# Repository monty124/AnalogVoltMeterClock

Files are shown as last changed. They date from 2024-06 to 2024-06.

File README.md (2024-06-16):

# AnalogVoltMeterClock
An AnalogVoltMeterClock 🤷‍♂️

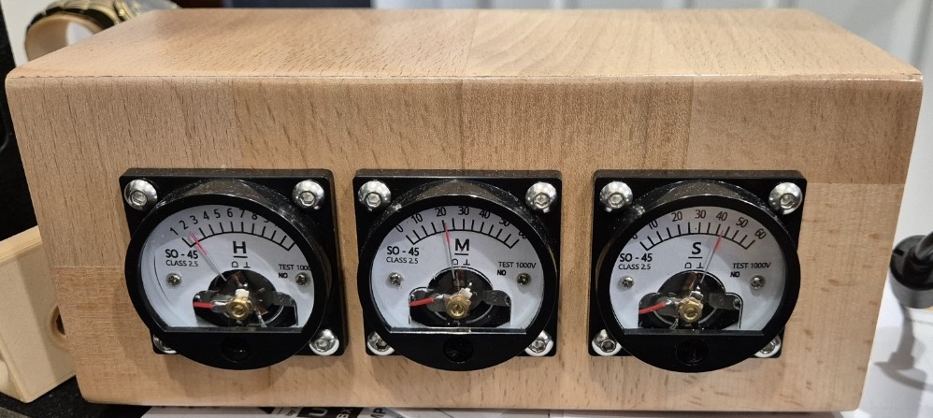
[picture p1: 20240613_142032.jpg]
  

# What is this?
Just a fun project to show the time in another way

Inspiration from:

- https://hackaday.io/project/163977-esp8266-wifi-ntp-voltmeter-clock
- https://michaelteeuw.nl/post/what-time-is-it-fathers-day
- https://github.com/MichMich/AnalogVoltMeterClock

# I want one

Sure, youll need:

### BOM

- An Enclosure, it needs to be big enough to fit the analog dials as well as the PCB (100x60) <br>
  There is a printable one that MAY work here https://www.thingiverse.com/thing:3437800 BUT i am unsure if my PCB will fit this enclosure. Zip Files are committed in this git repo if you want to try it; OR build without the PCB and hard wire to the ESP module and use this one.
- Optional 3D printed back or solid back, (make room for your power connection!)
- 3x Analog Voltmeter SO-45 style gauges (voltage unimportant) <br>
  https://www.aliexpress.com/item/1005003489268646.html <br>
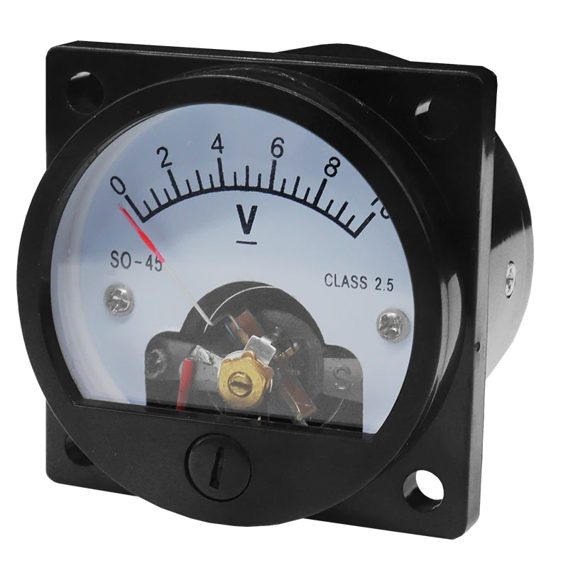
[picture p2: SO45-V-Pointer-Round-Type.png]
  
- 3x 3.9K Resistors OR any value between 2 - 5 K however you will need to work out your own calibration matrix
- PCB (gerber files are included [here](/AnalogVoltMeterClock/Gerber))
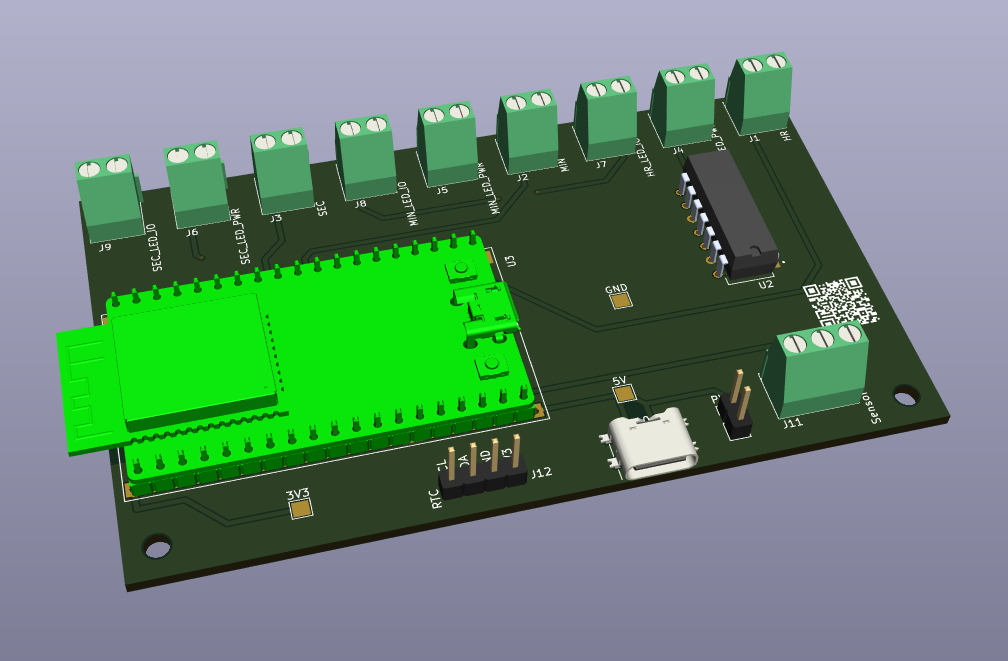
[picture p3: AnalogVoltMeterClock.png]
  
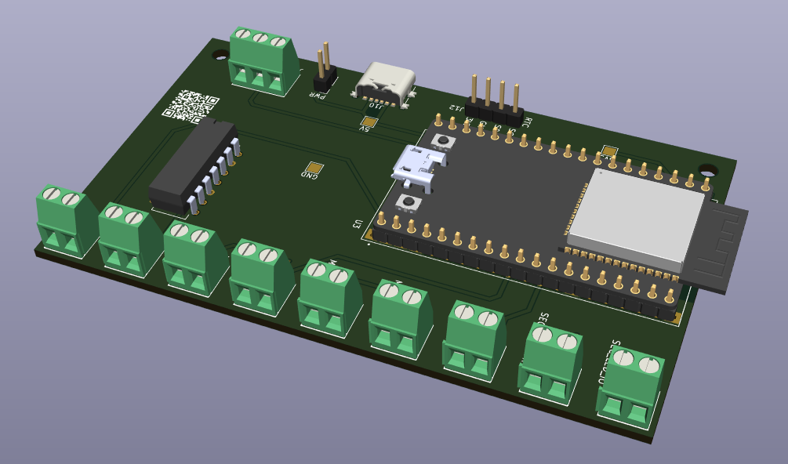
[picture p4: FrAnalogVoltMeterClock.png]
  
- "SW-420" Vibration Sensor <br>
  https://www.aliexpress.com/item/1005006205428052.html <br>
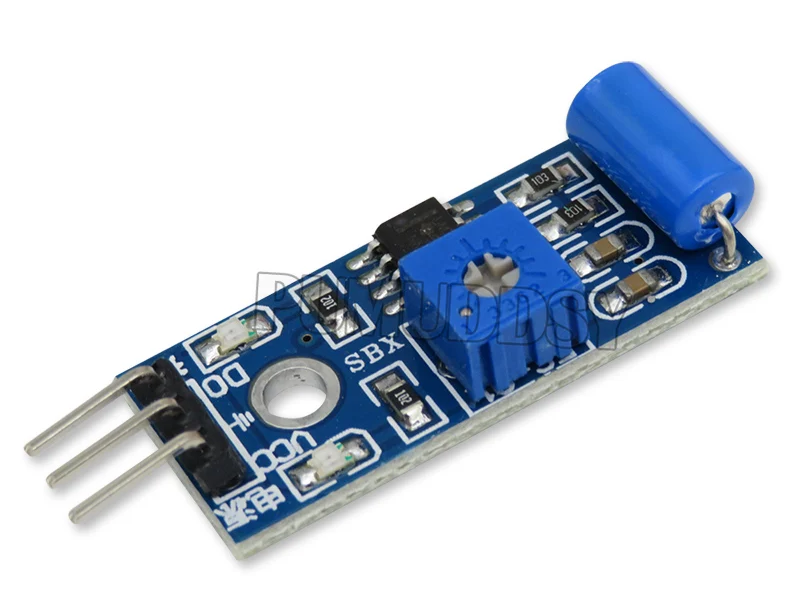
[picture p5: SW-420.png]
  
- "6 Pin" USB C Power socket OR panel mount DC socket and 5V power supply (use PWR header and omit USB) <br>
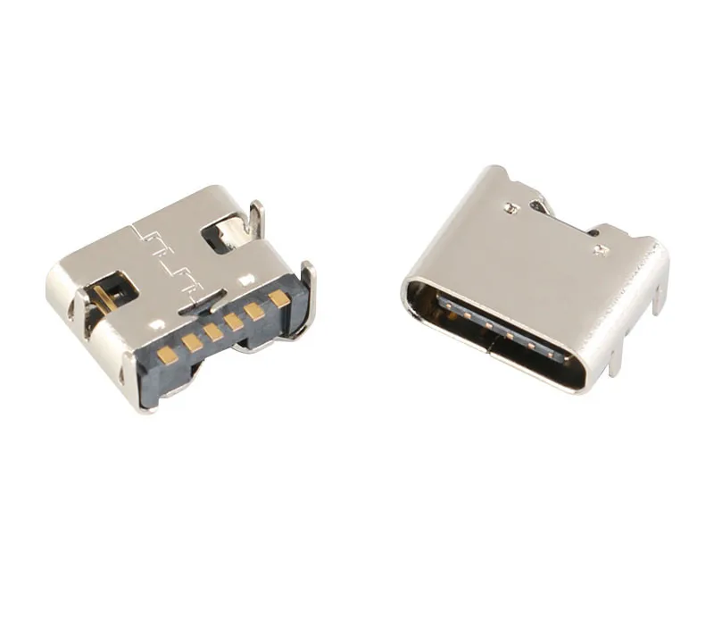
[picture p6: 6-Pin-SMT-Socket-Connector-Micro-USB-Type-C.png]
   <br>
  https://www.aliexpress.com/item/32976798070.html
- 3.5mm Pitch 2P and 3P Screw Terminals <br>
   https://www.aliexpress.com/item/4000874208361.html <br>
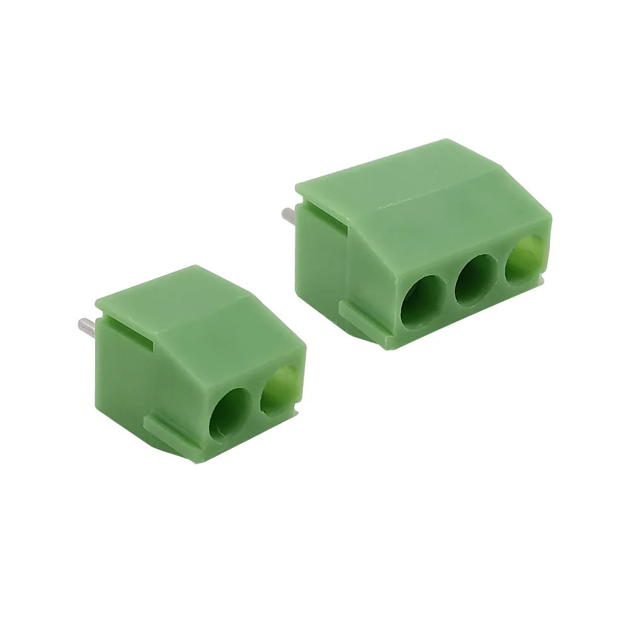
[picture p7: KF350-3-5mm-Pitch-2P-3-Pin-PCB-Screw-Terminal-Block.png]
    
- 1x FreeNove ESP32 WROOM 32E (not S3 variants) <br>
  https://store.freenove.com/products/fnk0090 or on Aliexpress<br>
  Note, Pinout of PCB is not compatible with other ESP modules like DevKit, etc <br>
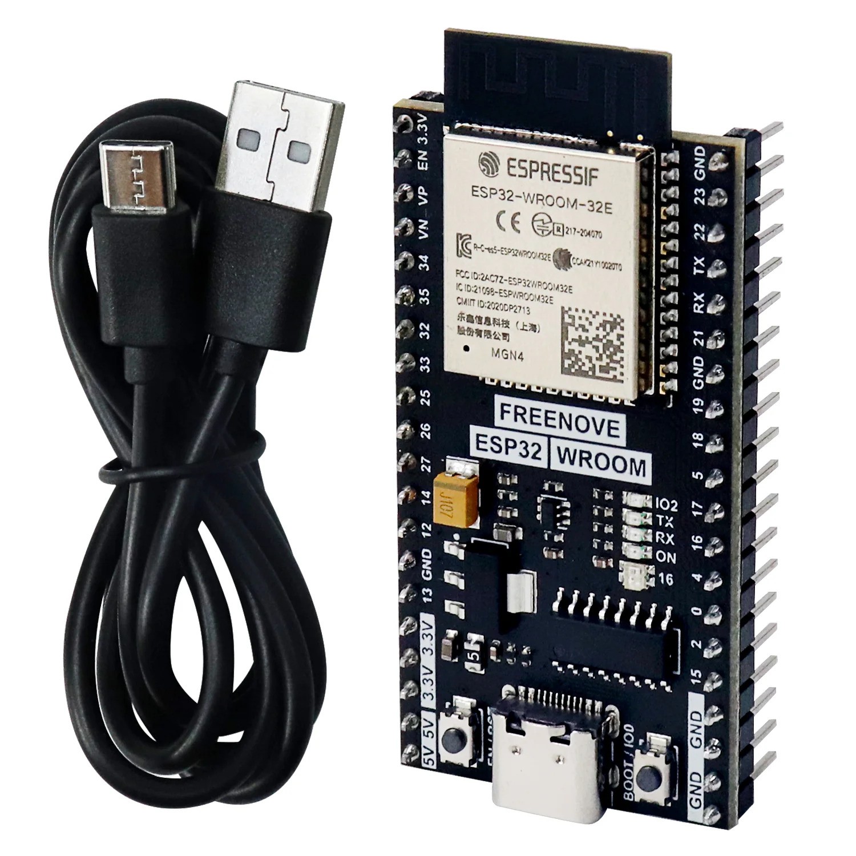
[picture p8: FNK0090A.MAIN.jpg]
 
- SN74AHCT125N IC <br>
 https://www.digikey.com.au/en/products/detail/texas-instruments/SN74AHCT125N/375798
- suitable 14Pin DIP Socket (optional) e.g. <br>
 https://www.digikey.com.au/en/products/detail/cnc-tech/245-14-1-03/3441580 <br>
- 2.54 Headers and Sockets (optional) <br>
  Socket 2x 20 pin for ESP module <br>
  Header for Power (if desired) <br>
- SK6812 LED's (ON PCB!) (if other variants are used like WS2812B you will need to debug the light: code block slightly) <br>
  https://esphome.io/components/light/index.html <br>
  n.b the White Channel is not important, can be WW, CW or NW <br>
  https://www.aliexpress.com/item/32961777888.html <br>
  https://www.aliexpress.com/item/1005002509850925.html <br>
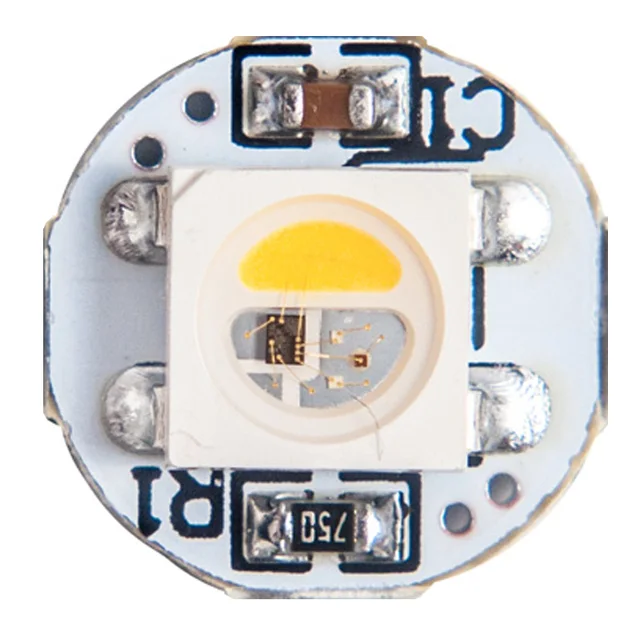
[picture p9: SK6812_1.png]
   <br>
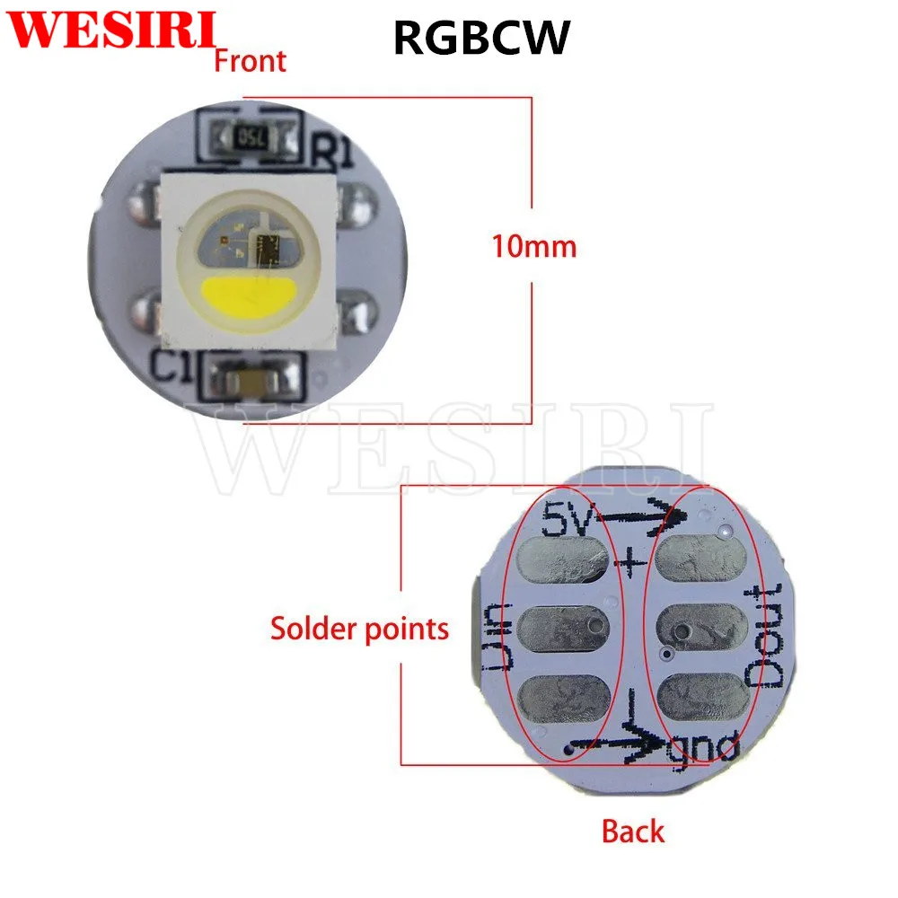
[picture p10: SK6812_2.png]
  <br>
- Silicone Hookup Wire and Crimps
- ESPHome Dev environment to build and deploy the Image <br>
  https://esphome.io/guides/getting_started_command_line <br>
  https://esphome.io/guides/getting_started_hassio <br>
- Cut and Printed [stickers](/Gauges)) to replace voltmeter gauge; use the PDF or the svg can be edited and printed with Inkscape https://inkscape.org/ <br>

# How To!

- Obtain your BOM items
- Build your enclosure!
- Dissasemble your gauges, replace the existing resistors with the 3.9K resistors, wire and mount your LED's <br>
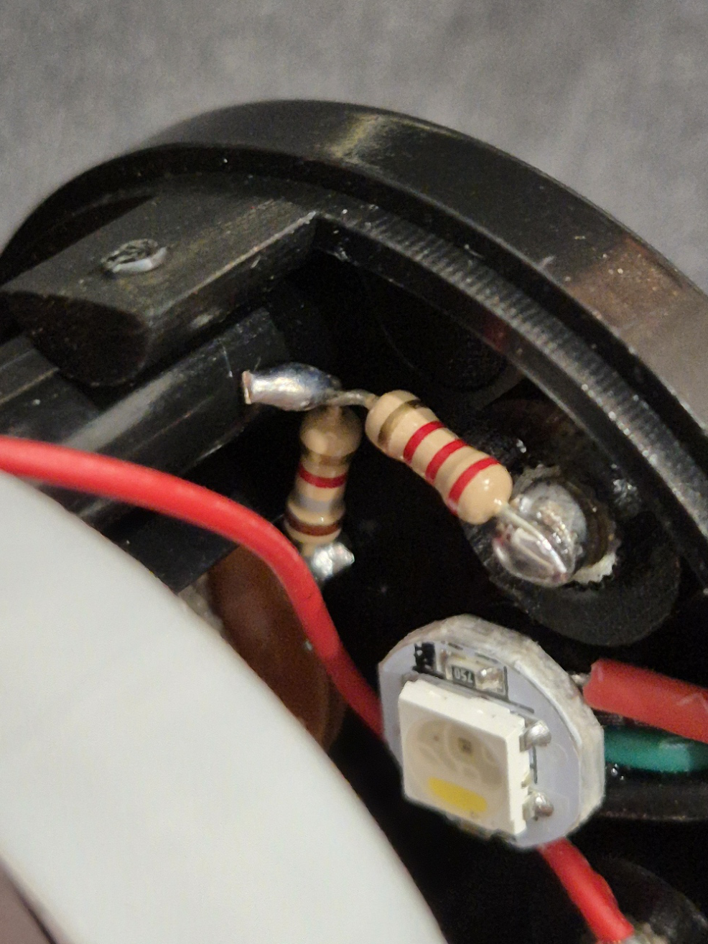
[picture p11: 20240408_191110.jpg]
   <br>
- Stick your gauge sticker over the original faceplace
- REASSEMBLE! <br>
   <br>
- Assemble your PCB
- Write the Base esphome image to your module https://web.esphome.io/ and connect to WIFI remember to also to include the `.h` files
- Edit the ESPHome Yaml file where required 
  - set MIN and MAX PWM
  - (optional) RGBW and Bright values
  - TimeZone (if not AEST) and or change to sntp see below
  - Disable Home Assistant api (remove encryption and key) if you dont use HA (also change time to sntp) <br>
    i.e:
    ```
    - platform: sntp
    #- platform: homeassistant
    timezone: Australia/Brisbane
    ```

- Build and Write the config to the module
- All should be working! 
- Connect to the Module Web Page and set LED colour
- Import into Home Assistant (optional)

# Calibration

[Excel sheets](/SpreadSheets) added to help calibrate! 

## PWM

- Use the Module web page to test values:
- Set Calibrate to ON <br>
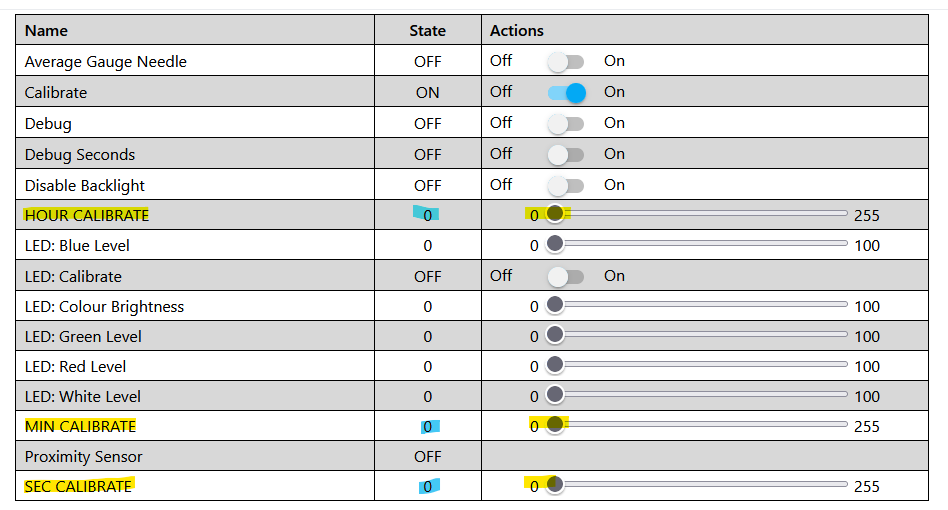
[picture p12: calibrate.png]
  <br>
- Find your MIN and MAX needle values for Hour, Minute and Second using the HOUR CALIBRATE, MIN CALIBRATE and SEC CALIBRATE Sliders, take note of the blue number <br>
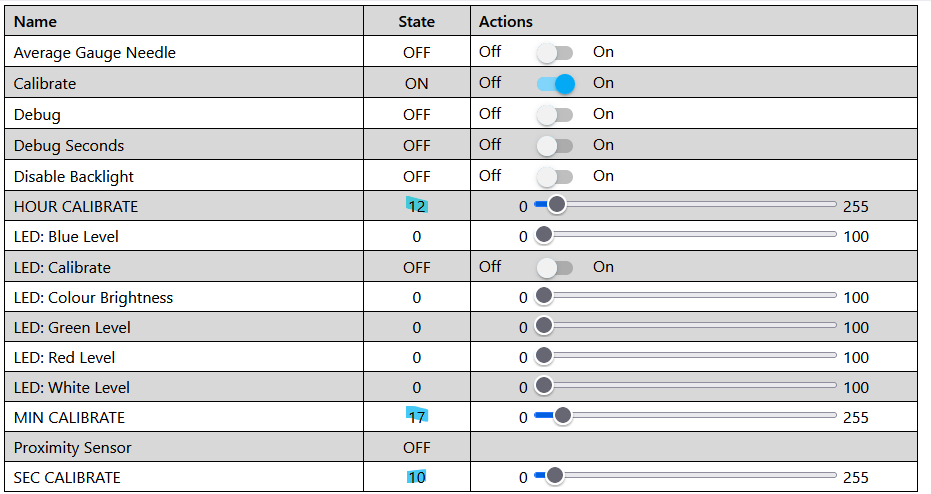
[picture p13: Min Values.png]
 <br>
- Min the needle should be set to the desired minimum value (for example minimum values): <br>
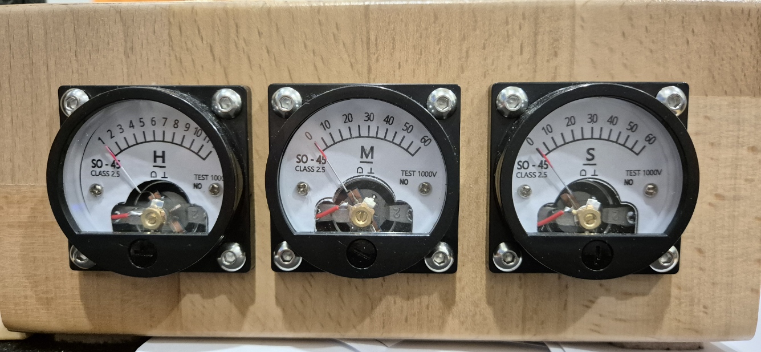
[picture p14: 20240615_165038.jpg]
 <br>
- Max is the same but the Maximum value (12 for Hour, and 60 for Min and Sec) <br>
- These numbers are recorded in the yaml file: <br>
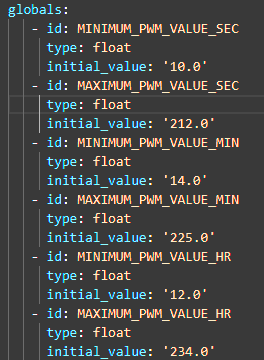
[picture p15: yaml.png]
   <br>
- This is the minimum amount of calibration required however you MUST set the "Average Gauge Needle" option to ON!

## Fine Tuned Calibration

- Continue to find each value and create a value MAP. <br>
- For example for Hour:
- find each PWM value for each number from 1 to 12
- Record the PWM values in `writeHandler.h` under `const int HOUR_NEEDLE[]` where each value represents the hour, the MAP works as such: <br>
  
  ```
  Midnight (12), 1 AM, 2, 3, 4, 5, 6, 7, 8, 9, 10, 11, 12, 1 PM, 2, 3, 4, 5, 6, 7, 8, 9, 10, 11
  ```

  DO NOT ALTER `const int HOUR_LOOKUP[]`

For Minute and Second there is a map for each second/minute, this can be performed by finding each PWM value per 5 interval (5 Seconds or 5 Minutes) THEN averaging the seconds and minutes in between. You are looking for as even as a spread between each minute/second represented as a whole integer 

  For example:

| Hour | PWM | Comment |
| :--: | :--: | :--: |
| 0 | 14 | measured |
| 5 | 30 | measured |
| 10 | 48 | measured |

| Hour | PWM | Comment |
| :--: | :--: | :--: |
| 0 | 14 | measured |
| 1 | 17 | averaged |
| 2 | 20 | averaged |
| 3 | 23 | averaged |
| 4 | 26 | averaged |
| 5 | 30 | measured |

Create a Map of all values and replace `const int SECOND_NEEDLE[]` and `const int MINUTE_NEEDLE[]`

You are able to fine tune the needle using the screw on the front of the dial

## LED

- enable LED: Calibrate
- To find your desired colour use 
  - LED: Blue Level
  - LED: Colour Brightness
  - LED: Green Level
  - LED: Red Level
  - LED: White Level

This value will save into eeprom but will not be retained if the module is reflashed, you can code these into the globals but!

## U2 Jumpers

The SN74AHCT125N can be a little .... sensitive and as we are only using one input and output a circuit has been built in where by if you accidently blow input/output 1A/1Y you can reconfgure the jumpers to use the other inputs and outputs! This avoids you throwing away an IC because one IO has failed. Hopefully.

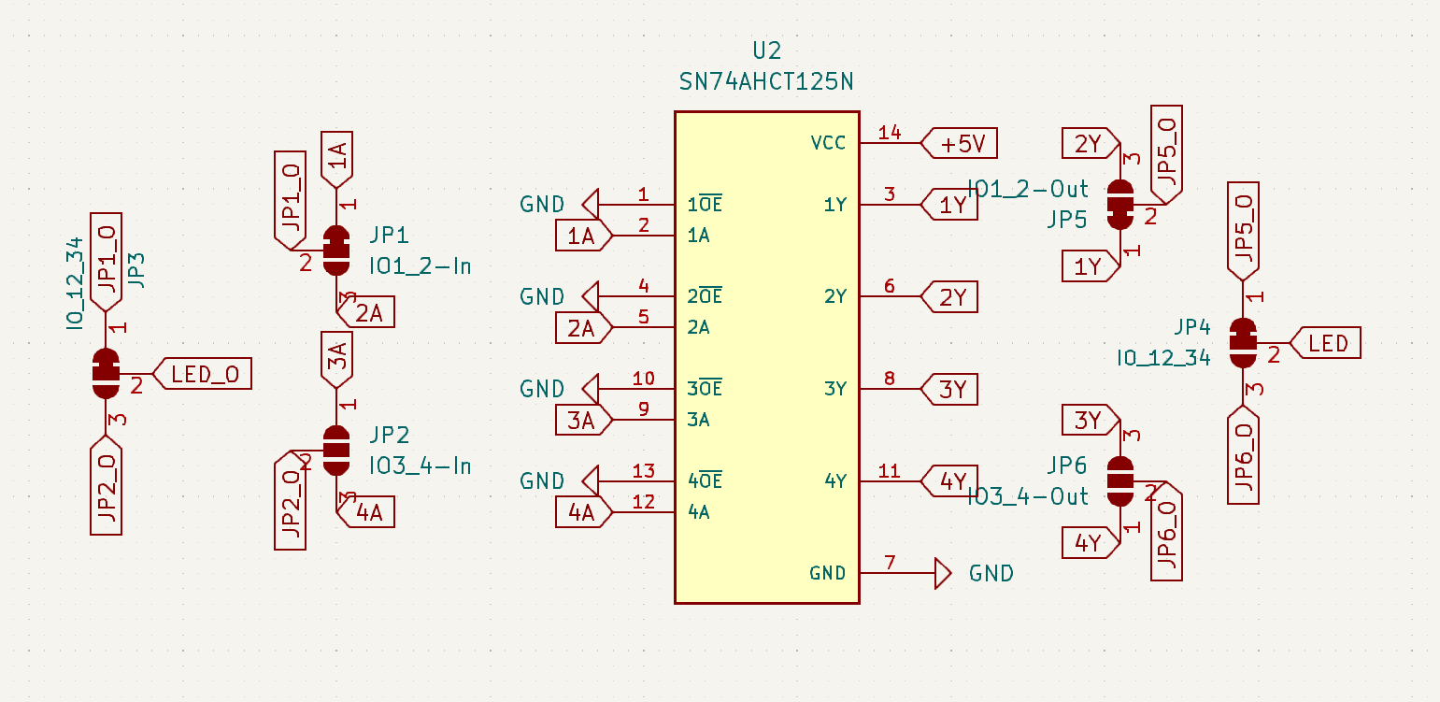
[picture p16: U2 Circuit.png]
 <br>

This table should help explain what jumpers you need to bridge. Note you will need to CUT the DEFAULT jumpers on JP3 and JP4 if you wish to use IO's 3 or 4, and cut the DEFAULT jumper on JP1 and JP5 to use IO 2

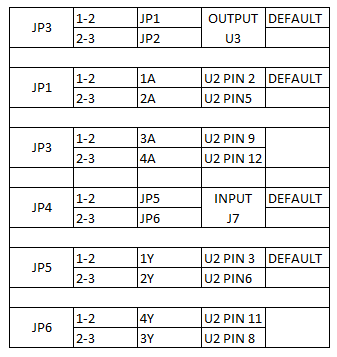
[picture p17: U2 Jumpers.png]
 <br>

More info can be found in the datasheet in the [repo](/sn74ahct125.pdf)

## To Do!

- Integrate a PCF8563 RTC module option for time keeping offline https://www.aliexpress.com/item/1005006438572175.html
- Code Improvements and tidy up
- ~~Excel sheet for calibration~~
- ~~Document matrix for IC~~
- 3D rear cover (STARTED!)
- Actual Assembly (still waiting on parts!)
- gif of movement

## I Wanna Contribute!

Sure, fork the repo and do ya thing then request a PR to merge!

## I found a bug or an Improvement!

As above OR open an Issue and lets see if we can fix

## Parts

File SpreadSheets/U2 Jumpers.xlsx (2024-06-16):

JP3 | 1-2 | JP1 | OUTPUT U3 | DEFAULT
 | 2-3 | JP2
JP1 | 1-2 | 1A | U2 PIN 2 | DEFAULT
 | 2-3 | 2A | U2 PIN5
JP3 | 1-2 | 3A | U2 PIN 9
 | 2-3 | 4A | U2 PIN 12
JP4 | 1-2 | JP5 | INPUT J7 | DEFAULT
 | 2-3 | JP6
JP5 | 1-2 | 1Y | U2 PIN 3 | DEFAULT
 | 2-3 | 2Y | U2 PIN6
JP6 | 1-2 | 4Y | U2 PIN 11
 | 2-3 | 3Y | U2 PIN 8

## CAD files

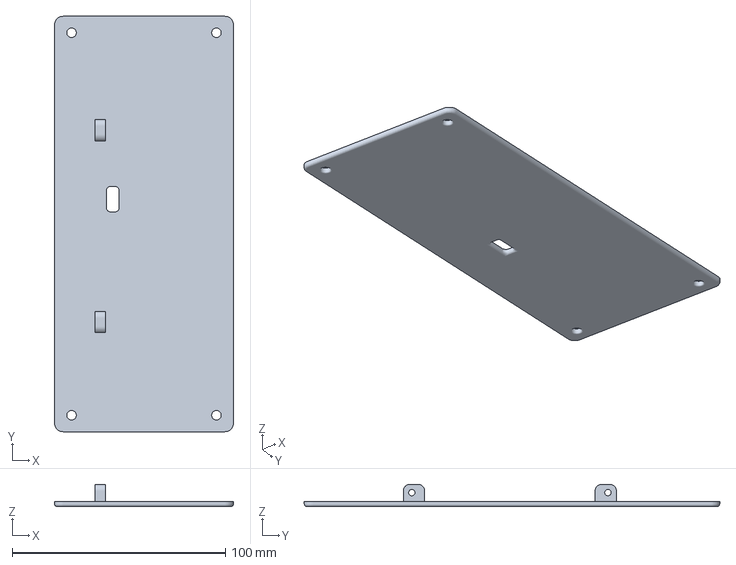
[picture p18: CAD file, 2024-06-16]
Back Panel/AnalogVoltMeterClock Back Panel.3mf
84.0 x 195.0 x 10.4 mm

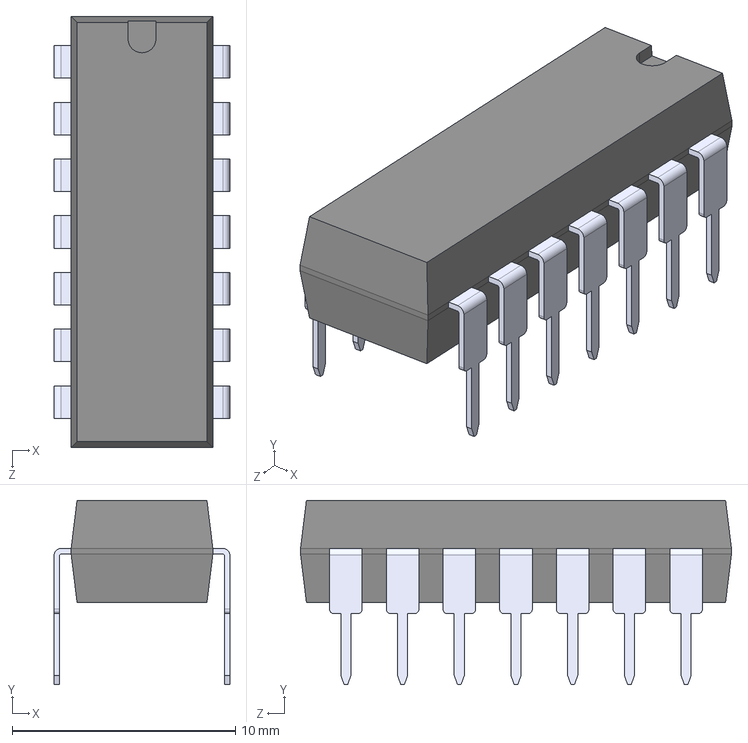
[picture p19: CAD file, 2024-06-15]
Symbols/SN74AHCT125N.step
7.87 x 8.26 x 19.3 mm

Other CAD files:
Back Panel/AnalogVoltMeterClock Back Panel.stl

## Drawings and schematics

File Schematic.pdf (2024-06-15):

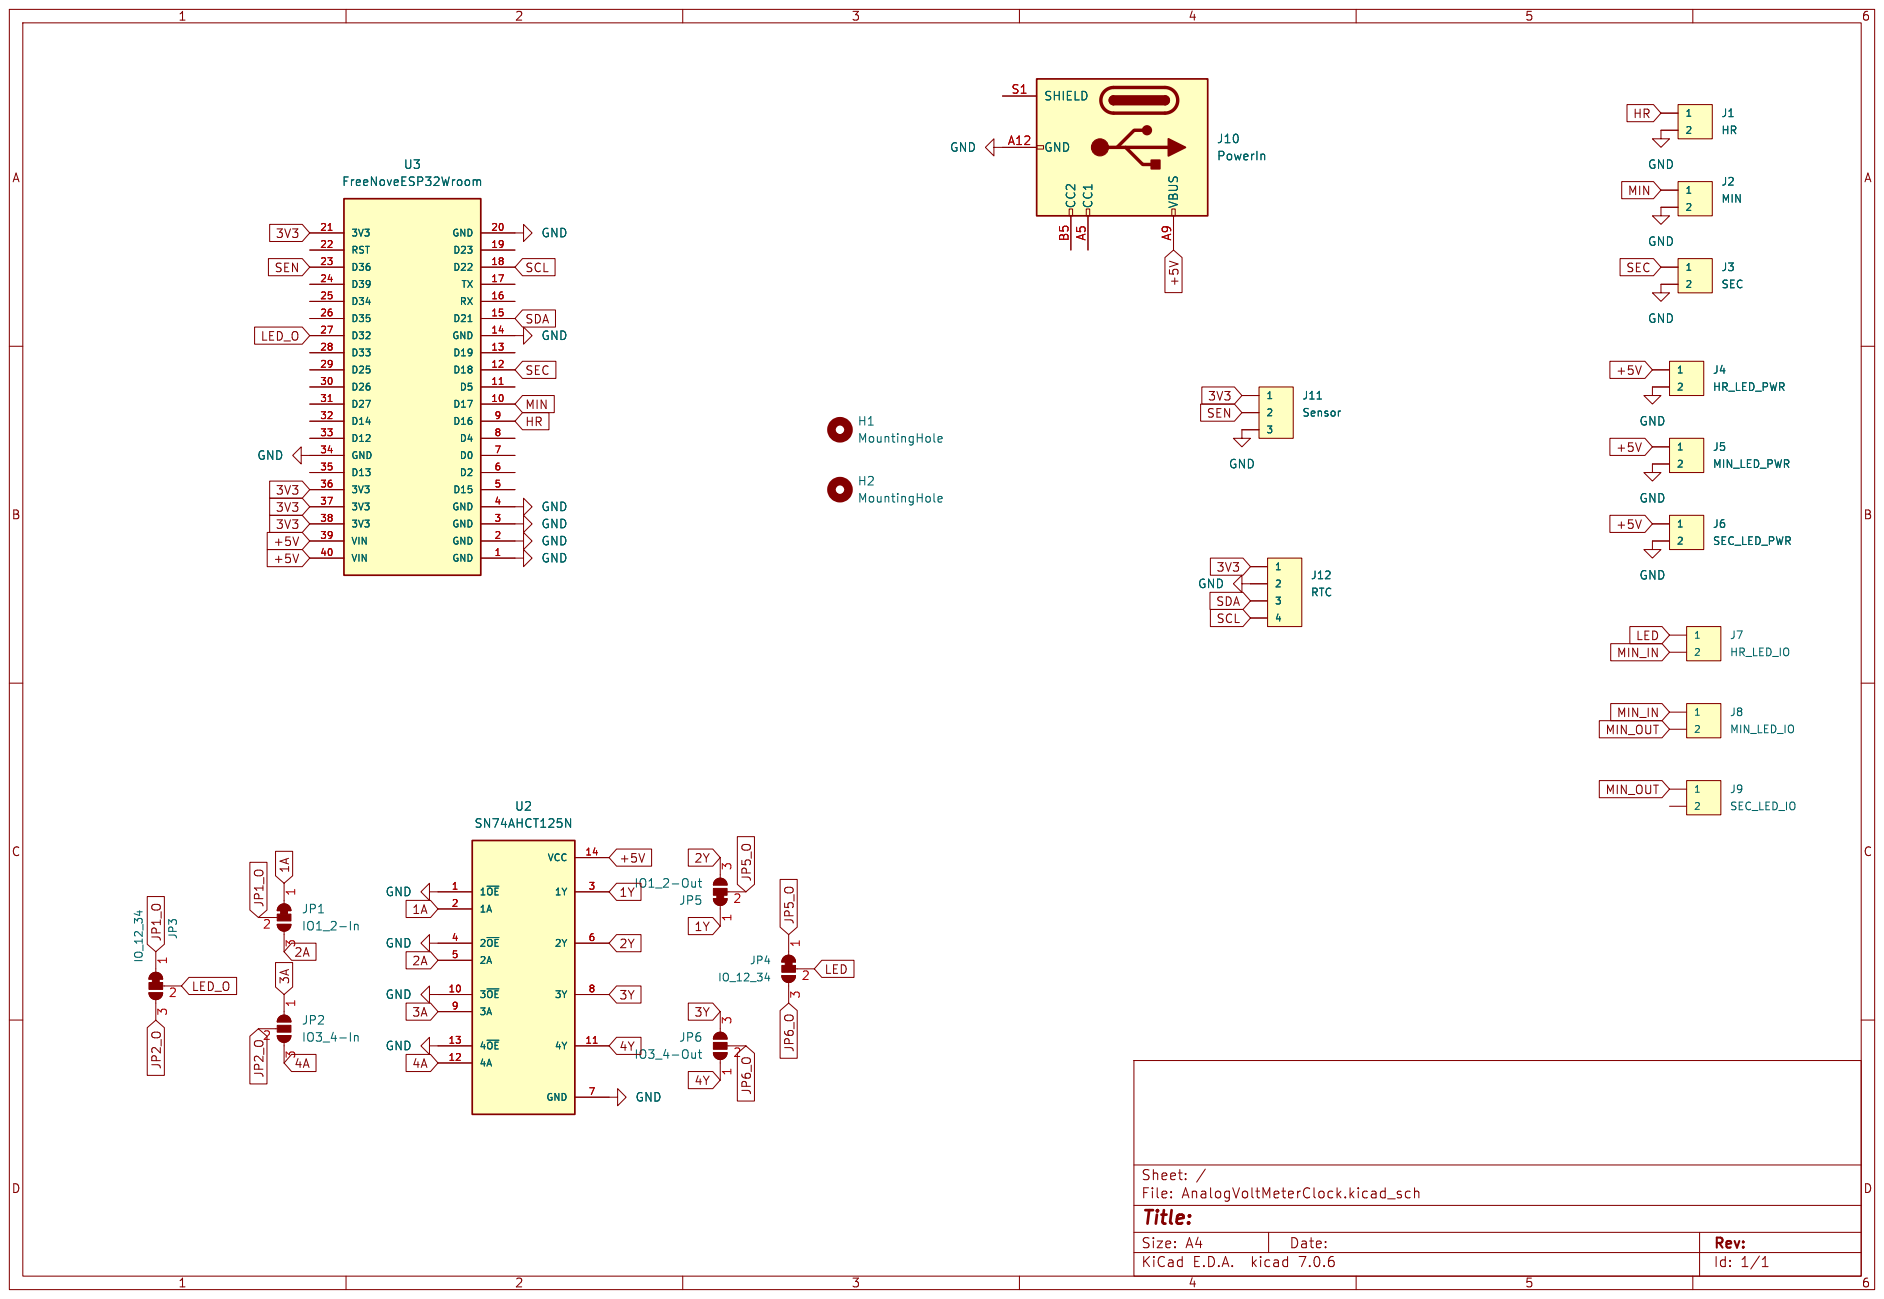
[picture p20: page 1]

GND GND GND GND GND GND GND

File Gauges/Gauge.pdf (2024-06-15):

SO - 45 | S
SO - 45 | H

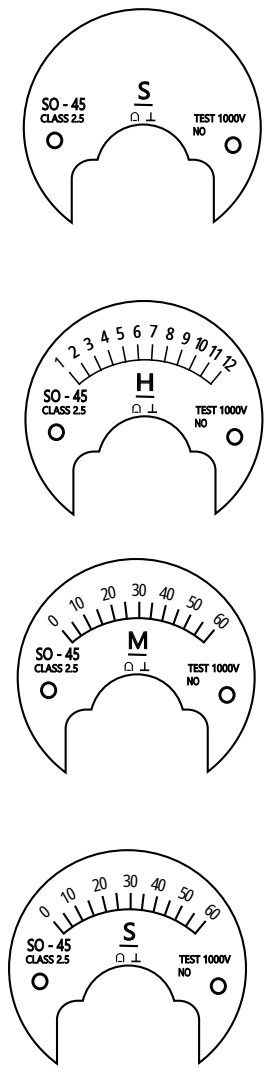
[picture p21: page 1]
CLASS 2.5; TEST 1000V

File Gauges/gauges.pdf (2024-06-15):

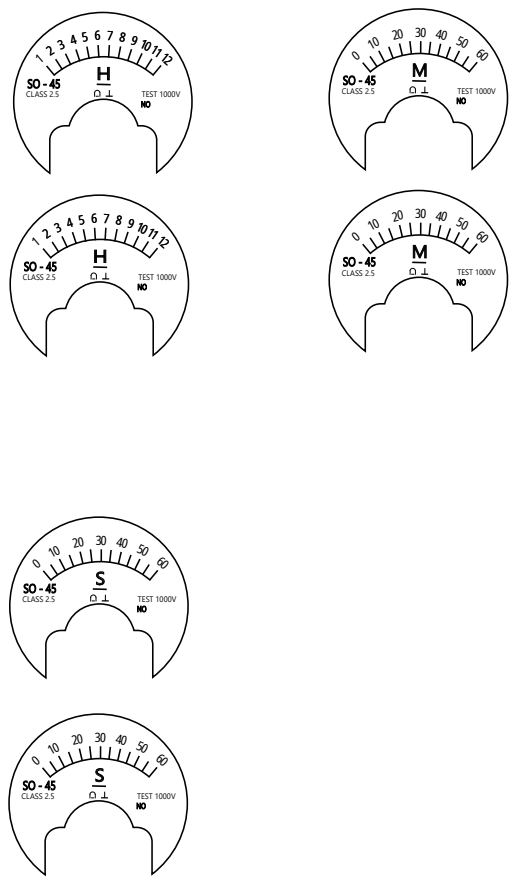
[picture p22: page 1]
CLASS 2.5; TEST 1000V

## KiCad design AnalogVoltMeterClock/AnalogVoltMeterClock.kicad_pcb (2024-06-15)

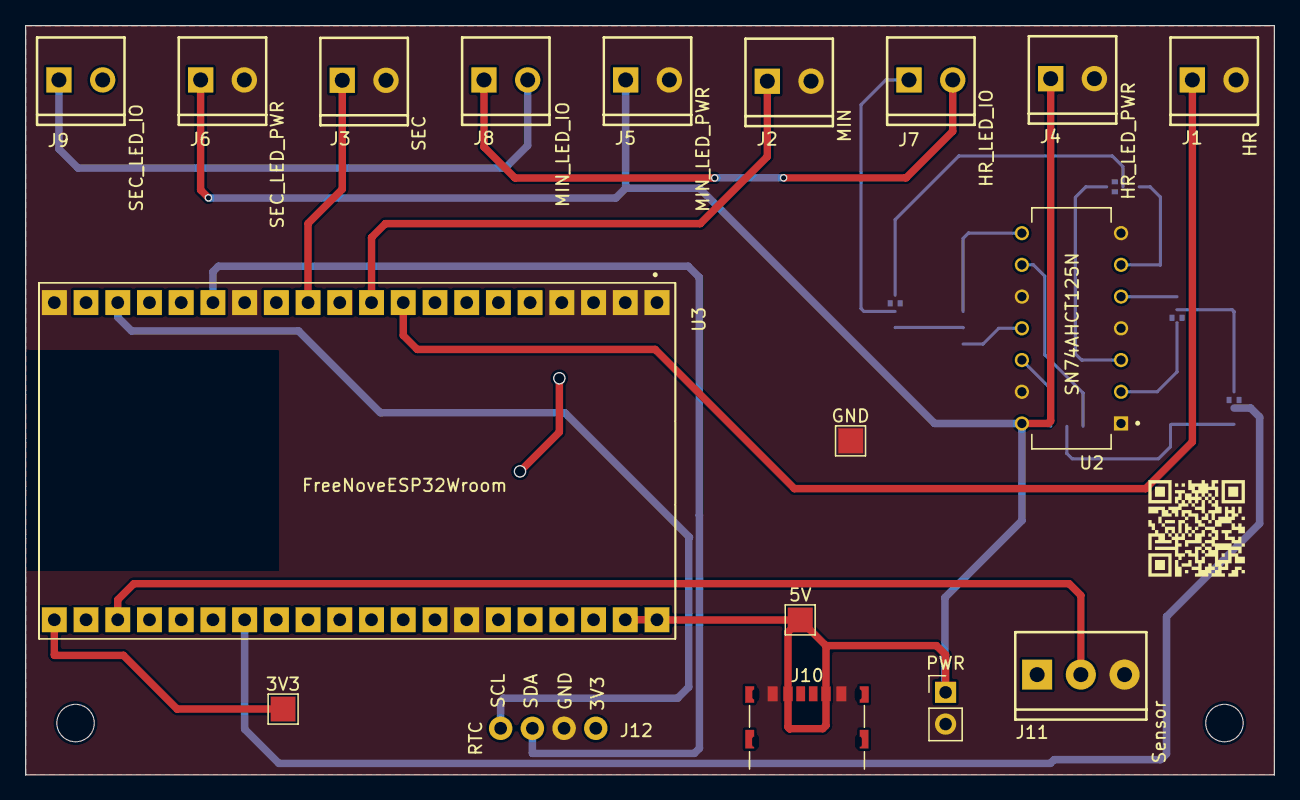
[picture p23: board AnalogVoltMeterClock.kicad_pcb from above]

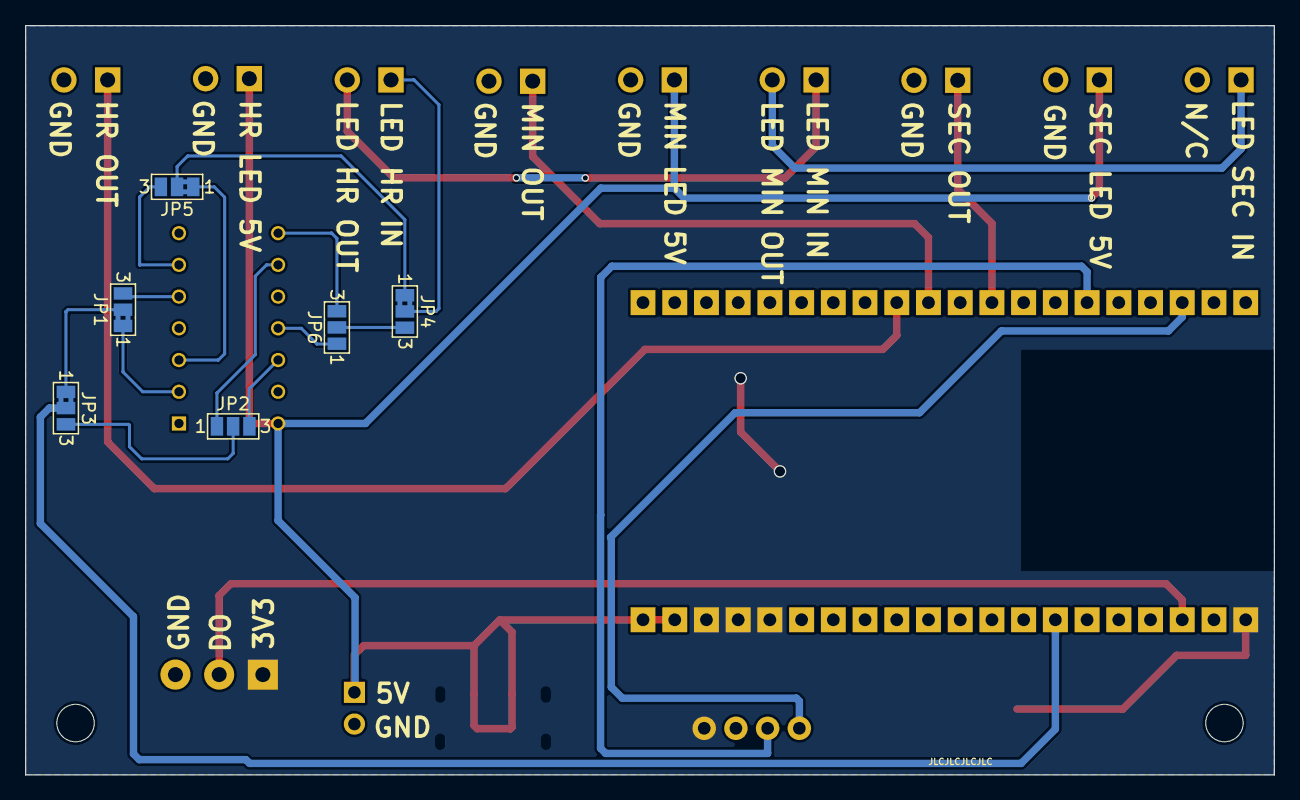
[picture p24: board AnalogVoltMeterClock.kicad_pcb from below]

Board: 2 copper layers, 100.0 x 60.0 mm, 26 parts (6 on the bottom side), 25 nets.

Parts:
3V3, 5V: TestPoint_Pad_2.0x2.0mm
GND: TestPoint_Pad_2.0x2.0mm
H1, H2: MountingHole; MountingHole_3mm
J1: HR; SCREWTERMINAL-3.5MM-2
J2: MIN; SCREWTERMINAL-3.5MM-2
J3: SEC; SCREWTERMINAL-3.5MM-2
J4: HR_LED_PWR; SCREWTERMINAL-3.5MM-2
J5: MIN_LED_PWR; SCREWTERMINAL-3.5MM-2
J6: SEC_LED_PWR; SCREWTERMINAL-3.5MM-2
J7: HR_LED_IO; SCREWTERMINAL-3.5MM-2
J8: MIN_LED_IO; SCREWTERMINAL-3.5MM-2
J9: SEC_LED_IO; SCREWTERMINAL-3.5MM-2
J10: PowerIn; USB_C_Receptacle_GCT_USB4135-GF-A_6P_TopMnt_Thru
J11: Sensor; SCREWTERMINAL-3.5MM-3
J12: RTC; 1X04
JP1: IO1_2-In; SolderJumper-3_P1.3mm_Bridged2Bar12_Pad1.0x1.5mm_NumberLabe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
JP2: IO3_4-In; SolderJumper-3_P1.3mm_Open_Pad1.0x1.5mm_NumberLabels
JP3, JP4: IO_12_34; SolderJumper-3_P1.3mm_Bridged2Bar12_Pad1.0x1.5mm_NumberLabe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
JP5: IO1_2-Out; SolderJumper-3_P1.3mm_Bridged2Bar12_Pad1.0x1.5mm_NumberLabe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
JP6: IO3_4-Out; SolderJumper-3_P1.3mm_Open_Pad1.0x1.5mm_NumberLabels
PWR: PinHeader_1x02_P2.54mm_Vertical
U2: SN74AHCT125N; DIP794W45P254L1930H508Q14
U3: FreeNoveESP32Wroom

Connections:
1A: JP1.1 (A), U2.2 (1A)
1Y: JP5.1 (A), U2.3 (1Y)
2A: JP1.3 (B), U2.5 (2A)
2Y: JP5.3 (B), U2.6 (2Y)
3A: JP2.1 (A), U2.9 (3A)
3V3: 3V3.1, J11.1, J12.1, U3.21 (3V3), U3.36 (3V3), U3.37 (3V3), U3.38 (3V3)
3Y: JP6.3 (B), U2.8 (3Y)
4A: JP2.3 (B), U2.12 (4A)
4Y: JP6.1 (A), U2.11 (4Y)
+5V: 5V.1, J4.1, J5.1, J6.1, J10.A9 (VBUS), J10.B9 (VBUS), PWR.1, U2.14 (VCC), U3.39 (VIN), U3.40 (VIN)
GND: GND.1, J1.2, J2.2, J3.2, J4.2, J5.2, J6.2, J10.A12 (GND), J10.B12 (GND), J11.3, J12.2, PWR.2, U2.1 (1~OE), U2.4 (2~OE), U2.7 (GND), U2.10 (3~OE), U2.13 (4~OE), U3.1 (GND), U3.2 (GND), U3.3 (GND), U3.4 (GND), U3.14 (GND), U3.20 (GND), U3.34 (GND)
HR: J1.1, U3.9 (D16)
JP1_O: JP1.2 (C), JP3.1 (A)
JP2_O: JP2.2 (C), JP3.3 (B)
JP5_O: JP4.1 (A), JP5.2 (C)
JP6_O: JP4.3 (B), JP6.2 (C)
LED: J7.1, JP4.2 (C)
LED_O: JP3.2 (C), U3.27 (D32)
MIN: J2.1, U3.10 (D17)
MIN_IN: J7.2, J8.1
MIN_OUT: J8.2, J9.1
SCL: J12.4, U3.18 (D22)
SDA: J12.3, U3.15 (D21)
SEC: J3.1, U3.12 (D18)
SEN: J11.2, U3.23 (D36)

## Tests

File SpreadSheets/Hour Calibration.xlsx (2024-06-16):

Dial Indicator | Actual PWM Value
1 | 12 |  | Use Calibrate to find your RED values and fill in the RED boxes
2 | 34
3 | 54
4 | 74
5 | 94
6 | 113
7 | 132
8 | 152
9 | 172 |  | {234,12,34,54,74,94,113,132,152,172,191,211,234,12,34,54,74,94,113,132,152,172,191,211}
10 | 191
11 | 211
12 | 234
 |  | Value:
 |  | {234,12,34,54,74,94,113,132,152,172,191,211,234,12,34,54,74,94,113,132,152,172,191,211}

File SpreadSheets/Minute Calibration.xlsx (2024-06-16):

Dial Indicator | Actual PWM Value | Calculated PWM Value |  | Dial Indicator | Actual PWM Value | Calculated PWM Value
0 | 14 |  |  | 31 |  | 123 | 3.4 | Use Calibrate to find your RED values and fill in the RED boxes
1 |  | 17 | 3.2 | 32 |  | 126 |  | Blue values will automatically calculate
2 |  | 20 |  | 33 |  | 129 |  | You are free to adjust where required in the Value block if they are too close or far apart!!
3 |  | 23 |  | 34 |  | 134
4 |  | 27 |  | 35 | 137
5 | 30 |  |  | 36 |  | 140 | 3.4
6 |  | 34 | 3.6 | 37 |  | 143.4
7 |  | 38 |  | 38 |  | 147
8 |  | 42 |  | 39 |  | 151 |  | {14,17,20,23,27,30,34,38,42,44,48,52,56,60,62,66,70,74,70,80,84,88,92,96,99,103,106,109,112,32,120,123,126,129,134,137,140,143.4,147,151,154,157,160,163,168,171,174,177,180,189,186,190,194,198,202,206,210,214,218,221,225}
9 |  | 44 |  | 40 | 154
10 | 48 |  |  | 41 |  | 157 | 3.4
11 |  | 52 | 3.6 | 42 |  | 160
12 |  | 56 |  | 43 |  | 163
13 |  | 60 |  | 44 |  | 168
14 |  | 62 |  | 45 | 171
15 | 66 |  |  | 46 |  | 174 | 3
16 |  | 70 | 3.6 | 47 |  | 177
17 |  | 74 |  | 48 |  | 180
18 |  | 70 |  | 49 |  | 189
19 |  | 80 |  | 50 | 186
20 | 84 |  |  | 51 |  | 190 | 4
21 |  | 88 | 3.8 | 52 |  | 194
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

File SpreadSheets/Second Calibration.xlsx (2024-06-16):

Dial Indicator | Actual PWM Value | Calculated PWM Value |  | Dial Indicator | Actual PWM Value | Calculated PWM Value
0 | 10 |  |  | 31 |  | 113 | 3.2 | Use Calibrate to find your RED values and fill in the RED boxes
1 |  | 13 | 3 | 32 |  | 116 |  | Blue values will automatically calculate
2 |  | 16 |  | 33 |  | 119 |  | You are free to adjust where required in the Value block if they are too close or far apart!!
3 |  | 19 |  | 34 |  | 123
4 |  | 22 |  | 35 | 126
5 | 25 |  |  | 36 |  | 129 | 3
6 |  | 28 | 3.4 | 37 |  | 132
7 |  | 31 |  | 38 |  | 135
8 |  | 34 |  | 39 |  | 138 |  | {10,13,16,19,22,25,28,31,34,39,42,46,50,54,56,60,63,66,63,74,77,81,85,89,91,95,98,101,104,32,110,113,116,119,123,126,129,132,135,138,141,144,147,150,155,158,161,164,167,177,174,177,180,183,188,191,195,199,203,208,212}
9 |  | 39 |  | 40 | 141
10 | 42 |  |  | 41 |  | 144 | 3.4
11 |  | 46 | 3.6 | 42 |  | 147
12 |  | 50 |  | 43 |  | 150
13 |  | 54 |  | 44 |  | 155
14 |  | 56 |  | 45 | 158
15 | 60 |  |  | 46 |  | 161 | 3.2
16 |  | 63 | 3.4 | 47 |  | 164
17 |  | 66 |  | 48 |  | 167
18 |  | 63 |  | 49 |  | 177
19 |  | 74 |  | 50 | 174
20 | 77 |  |  | 51 |  | 177 | 3.4
21 |  | 81 | 3.6 | 52 |  | 180
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

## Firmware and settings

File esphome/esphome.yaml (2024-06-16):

substitutions:
  name: esphome-web-c38990 #may want to change the name here
  friendly_name: FreeNoveDev #and here

esphome:
  name: ${name}
  friendly_name: ${friendly_name}
  name_add_mac_suffix: false
  includes:
    - writeHandler.h
    - bootHandler.h
  project:
    name: esphome.web
    version: '1.0'
  on_boot:
    - priority: 600 
      then: 
        - lambda: |-
            BootAnimation::startSequence();    

## CONFIG START

## Note, Timezone needs to be set under time component

globals:
   - id: MINIMUM_PWM_VALUE_SEC
     type: float
     initial_value: '10.0'
   - id: MAXIMUM_PWM_VALUE_SEC
     type: float
     initial_value: '212.0'
   - id: MINIMUM_PWM_VALUE_MIN
     type: float
     initial_value: '14.0'
   - id: MAXIMUM_PWM_VALUE_MIN
     type: float
     initial_value: '225.0'
   - id: MINIMUM_PWM_VALUE_HR
     type: float
     initial_value: '12.0'
   - id: MAXIMUM_PWM_VALUE_HR
     type: float
     initial_value: '234.0'
   - id: HOUR_PIN
     type: int
     initial_value: '16'
   - id: MINUTE_PIN
     type: int
     initial_value: '17'
   - id: SECOND_PIN
     type: int
     initial_value: '18'
   - id: DEBUG_ON
     type: bool
     initial_value: 'true'
   - id: DEBUG_SECOND_ON
     type: bool
     initial_value: 'false'
   - id: CALIBRATE
     type: bool
     initial_value: 'false'
   - id: AVERAGE
     type: bool
     initial_value: 'false'
   - id: RED
     type: float
     restore_value: True
     initial_value: '0.0'
   - id: GREEN
     type: float
     restore_value: True
     initial_value: '0.0'
   - id: BLUE
     type: float
     restore_value: True
     initial_value: '0.0'
   - id: WHITE
     type: float
     restore_value: True
     initial_value: '0.0'          
   - id: BRIGHT
     type: float
     restore_value: True
     initial_value: '0.0'
   - id: BACKLIGHT
     type: bool
     restore_value: True
     initial_value: 'true'

wifi:
    ssid: !secret wifi_ssid_24 #set your secrets in esphome
    password: !secret wifi_password #set your secrets in esphome
    ap:
      ssid: ${name}
      password: !secret local_ap_pw #set your secrets in esphome
                         

# Enable Home Assistant API
api:
  encryption:
    key: !secret api_key_freenove #set your secrets in esphome

## NO CONFIG BELOW HERE

esp32:
  board: esp32dev
  framework:
    type: arduino

logger:
  level: DEBUG
    
ota:

captive_portal:

web_server:
  port: 80

switch:
  - platform: template
    name: "Debug"
    optimistic: True
    id: "debug"
    on_turn_on: 
      then:
        - globals.set: 
            id: DEBUG_ON
            value: 'true'
    on_turn_off: 
      then:
        - globals.set: 
            id: DEBUG_ON
            value: 'false'
  - platform: template
    name: "Debug Seconds"
    optimistic: True
    id: "debug_sec"
    on_turn_on: 
      then:
        - globals.set: 
            id: DEBUG_SECOND_ON
            value: 'true'
    on_turn_off: 
      then:
        - globals.set: 
            id: DEBUG_SECOND_ON
            value: 'false'
  - platform: template
    name: "Average Gauge Needle"
    optimistic: True
    id: "average"
    on_turn_on: 
      then:
        - globals.set: 
            id: AVERAGE
            value: 'true'
    on_turn_off: 
      then:
        - globals.set: 
            id: AVERAGE
            value: 'false'
  - platform: template
    name: "Calibrate"
    optimistic: True
    id: "calibrate"
    on_turn_on: 
      then:
        - globals.set: 
            id: CALIBRATE
            value: 'true'
        - lambda: |-
              analogWrite( id(HOUR_PIN), 0);
              analogWrite( id(MINUTE_PIN), 0);
              analogWrite( id(SECOND_PIN), 0);
    on_turn_off: 
      then:
        - globals.set: 
            id: CALIBRATE
            value: 'false'
        - lambda: |-
                auto time = id(esptime).now();
                WritePinValue::SecondHandle(id(SECOND_PIN), time.second);
                WritePinValue::MinuteHandle(id(MINUTE_PIN), time.minute);
                WritePinValue::HourHandle(id(HOUR_PIN), time.hour);            
  - platform: template
    name: "LED: Calibrate"
    optimistic: True
    id: "calibrateled"
    assumed_state: False
    on_turn_on: 
      then:
        - light.turn_on: backlight
    on_turn_off: 
      then:
        - light.turn_off: backlight
  - platform: template
    name: "Disable Backlight"
    optimistic: True
    id: "disablebacklight"
    on_turn_on: 
      then:
        - globals.set: 
            id: BACKLIGHT
            value: 'true'
    on_turn_off: 
      then:
        - globals.set: 
            id: BACKLIGHT
            value: 'false'
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

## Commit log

2024-06-15 Create Schematic.pdf
    Added Schematic
2024-06-16 Spreadsheets added!
    [AnalogVoltMeterClock Back Panel.stl, Hour Calibration.xlsx, Minute Calibration.xlsx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]
